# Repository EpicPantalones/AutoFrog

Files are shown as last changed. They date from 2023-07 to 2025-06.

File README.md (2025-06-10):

# AutoFrog
Welcome to AutoFrog.

This project has been deprecated in favor of AutoFrog 2.0, which is another repository I own.
## File Tree
### design
contains design files, commentary, etc. as well as the project overview and software/hardware descriptions.
### server
contains all the files and config to run on the Rpi Zero.
## userend
contains the user application and associated files.

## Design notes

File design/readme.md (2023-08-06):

# Project Overview
## Original Request
"Two cages, with misters, lights and fans, all running off 120V AC power. All devices need to be controlled by a single controller. Devices will need to be turned on/off at reprogrammable times of day, with multiple on/off times per device. Programs need to be programmable down to 1-sec intervals. Will need to track time of day, so that programs run at the same times. Need to be able to have different programs for all devices, and every day of the week. Need to be able to measure humidity and use the humidity to control the fans, based on a user set threshold. want the ability to recover from power loss and update time of day and put lights back into the state they were prior to power loss. Misters should ALWAYS start in the OFF state after power loss and NOT return to on, if they were running when power goes out. Would like a webpage to set the config file if possible, but need a way to modify programs as applicable. would be nice if RTC autochanged with daylight savings time and autosynced to remove clock drift. electric power needs to be in a box that protects any circuitry from being contacted inadvertantly."
### Device channels (by cage)
2 lights \
1 mister \
1 fan

## Electrical block diagram
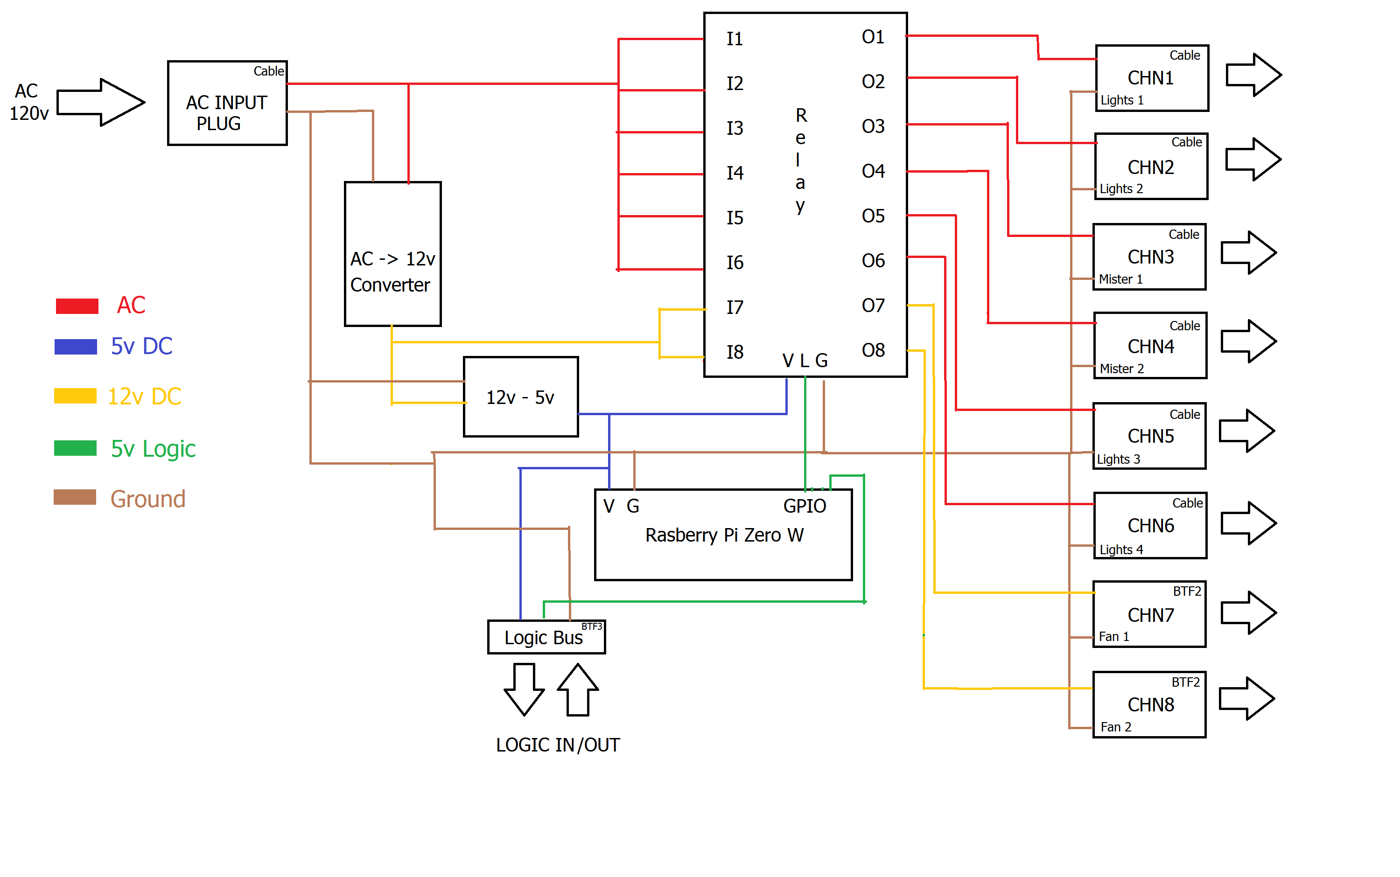
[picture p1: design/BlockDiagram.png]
Block Diagram

System has one AC input and one input on the logic bus. Has six AC channel outputs, which will vary in size depending on requirement, as well as two 12v outputs and 1 logic bus for humidity sensing. Note that for simplicity, the earth ground is omitted, and the neutral wires all connect to the same line regardless of voltage.
### Design
The power is inputted directly from 120v AC through a C13 connector with a protective fuse. This also has the master power switch. From there the power is split into two branches. The first is the AC line that goes directly to six of the eight channels on the relay, for the six AC outputs. The second branch goes to a 12v converter, which in turn produces two branches of 12v DC power: one for powering the two 12v channels, and one that is further downconverted to a 5v supply for the raspberry pi and the logical power input of the relay. The raspberry Pi's logical output is 3.3v, so there is a small level converter for the 5v required on the relay. The ground to the LC comes from the Rpi, and Va and Vb are supply by directly wiring to their respective supplies. The raspberry Pi also sends a wire out to the outside which allows the humidity sensor to send data back.

## Mechanical Design
We purchased a small clear box to contain all the circuitry. Due to time constraints, the harnessing and box are a bit rushed, but the box provides ample protection and does a good job supporting both the standoffs for the circuitry and the output connectors. Also due to the time contraints, there was not enough time to measure all of the wires, so the harnessing is not nearly as neat as I would like it to be. Next time, I would do a better job of designing the wiring layout before beginning execution of the build phase.

## Materials List:
The full list of items purchase is on amazon, link here: \
https://www.amazon.com/hz/wishlist/ls/33Y2IXWOOTIRV/ref=nav_wishlist_lists_3

### Items
- **Raspberry Pi Zero W**: the brains.
- **MicroSD card**: minimum 16GB. houses OS for Rpi
- **AZDelivery Humidity Sensor**: measures humidity in the cages to control fan speed.
- **12v DC Power Supply**: Modified standard 12v power supply. Removed the AC type A connector and barrel plug output and used just the bare wiring.
- **5v DC Converter**: downconverts the 12V line for Rpi and humidity sensors.
- **Sunfounder 8 Chn Relay**: Takes in AC or DC power and acts as a digitally controlled switch. Logical is controlled on a 5v level, which must be powered seperately from the host device.
- **HiSense Logic Level Convertor**: converts the logic level of the Rpi (3.3v) to the level of the relay (5v).
- **3Dman 15 Rocker Connector**: Used as system input, a C13 connector with a 5A fuse and a rocker switch. Fuse can be swapped for 10A if necessary.
- **Panel mount AC outlets**: Used as the channel outputs for the 6 AC channels.
- **BTF-Lightning connectors**: 2 pin version used as the connections for the 12v channels and the 3 pin version used to connect to the humidity sensor. In reality I should have gotten 2 connectors for 2 voltages, but it was a tactical decision...
- **Various Types of Wire, Standoffs, Suction Cups**

## Software Design
### Overview
Using the userend GUI, users can create and assign channels and configurations remotely from their machine. Upon confirmation, the GUI sends those configurations to the Rpi Zero, which receives them and immediately loads them into the system. The Rpi Zero has a default state in the event of power loss, and will automatically come online and begin listening again after rebooting. Users can also change the state of the channels manually, which persists until the next event in the current config file. There may be any number of configuration files, and not all configuration files are required to be assigned to a channel. Channels may share a configuration.
### User End
User Gui was designed with Tkinter, and has two main modes: configuration mode, and live command mode. In configuration mode, users may add, remove, or edit files to create custom times for the channels to be considered ON or OFF. in Live command mode, users can see the active status of the channels and can send commands to change the state of channels.
### Server
The server end uses threads to listen for commands and other than that controls some global variables that are used to determine the configuration of the system. The server controls the channels down to the second level, but it should also be noted that the inputs can only come at the minute level.

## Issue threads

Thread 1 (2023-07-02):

Purchase Approvals

EpicPantalones, 2023-07-02:
In design/readme is the current list of materials needed, as well as the link to the amazon page. I need you to read through them and approve them or bring them up for review. Yeet

sirgunthercakes, 2023-07-03:
approve all

Closed 2023-07-03.

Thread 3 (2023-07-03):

Purchase Order

EpicPantalones, 2023-07-03:
Purchasing info for the approved items. 15 items comes out to $206.37. Will wait for confirmation before purchase. Do not close this issue.

sirgunthercakes, 2023-07-03:
approve

EpicPantalones, 2023-07-03:
Order# 113-9573016-7701869 placed. Items arriving July 3 and July 6. Will post updates

EpicPantalones, 2023-07-04:
The following arrived today (now 4/13):
2 pin BTF-Lightning connectors
12v Power Supply
AZDelivery Humidity sensor
Suction cups

sirgunthercakes, 2023-07-06:
arrived 7/5
3 pin BTF lightning connectors
16 ga cable
20 ga cable
3 pin insulated cable
power rocker ac input
ac output plugs
5 volt converter
standoffs
8 channel relay
rpi zero-w

Closed 2023-07-06.

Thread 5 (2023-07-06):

Testing Checklist

EpicPantalones, 2023-07-06:
The following test must be completed for the design to be considered complete:
**Hardware Tests**
- [ ] 12v Regulator output tested
- [ ] 5v Regulator output tested
- [ ] channeled relay tested to ensure proper toggles
- [ ] Rpi outputs tested
- [ ] Humidity sensor gives valid data
- [ ] Items stay securely in mechanical housing
- [ ] AC input tested

**Software Tests**
- [ ] Rpi can read humidity sensor
- [ ] Rpi can toggle switches on and off
- [ ] Rpi can communicate across socket
- [ ] Rpi can receive input from user endpoint
- [ ] Rpi software restarts properly after power-loss

Tests may be added or removed within this thread. _Do not mark this issue as complete_

EpicPantalones, 2023-07-14:
New Test:
- [ ] logic shifter successfully changes from 3.3 to 5v

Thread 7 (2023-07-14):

Hardware Testing Results

EpicPantalones, 2023-07-14:
The following items were tested:

1. AC input plug - we discovered that the LOAD wire is the BLUE wire, the NEUTRAL is the RED, and the GROUND is the YELLOW.
2. 12 V adapter - outputs steady at 12.3V
3. 5 V adapter - outputs steady at 5.02V
4. 8 Channel relay - the part functions just fine. Note - we should use the right pair of inputs so that it defaults to CLOSED in a powered state.
5. Rasberry Pi Zero - we tested the GPIO using gpio_test.py. It turns out that Rpis operate at a 3.3V logic level, so we are purchasing new logic shifters to get the output we need for the relay.

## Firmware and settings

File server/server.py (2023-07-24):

import threading
import socket
import os

CWD = os.getcwd()
KILLSWITCH = True
'''
Socket server runs on an infinite loop. You can start it in a thread
to prevent the server from blocking the rest of the program.
'''
def start_socket_server(host, port):
    # Create a TCP socket
    server_socket = socket.socket(socket.AF_INET, socket.SOCK_STREAM)
    
    # Bind the socket to the host and port
    server_socket.bind((host, port))
    
    # Listen for incoming connections
    server_socket.listen(1)
    print(f"Server started. Listening on {host}:{port}")
    
    try:
        while KILLSWITCH:
            # Accept a connection
            client_socket, client_address = server_socket.accept()
            print(f"Accepted connection from: {client_address}")
            
            # Handle the client connection in a new thread
            threading.Thread(target=handle_client, args=(client_socket,)).start()
    finally:
        server_socket.close()

'''
handle_client spawns everytime the server gets a connection. It receives
a message and then directs it into handle_message, where a message is returned.
'''
def handle_client(client_socket):
    while True:
        # Receive data from the client
        data = client_socket.recv(1024).decode()
        
        if not data:
            break  # No more data received, exit the loop
        
        # Handle the received message in a new thread
        threading.Thread(target=handle_message, args=(client_socket, data)).start()

    # Close the client socket
    client_socket.close()

'''
handle_message will perform the action from the server
spawns from the thread handle_client
'''
def handle_message(client_socket, message):
    # DEBUG Printing the received message
    print(f"Received message: \"{message}\"")
    OK = True
    args = message.split()
    print(args)
    commands = ["UPDATEREGISTRY","REQUESTLIVESTATUS","LIVECOMM"]
    if args[0] not in commands:
        response = "ERROR comm-not-recognized"
    else:
        if args[0] == "UPDATEREGISTRY":
            reached = False
            edits = []
            deletes = []
            for i,arg in enumerate(args):
                if i == 0:
                    continue
                if arg == "DELETES":
                    reached = True
                elif reached:
                    deletes.append(arg)
                else:
                    edits.append(arg)
            # function that will update system
            print(f"edits:{edits}")
            print(f"deletes:{deletes}")
            response = "RECEIVED"
        elif args[0] == "REQUESTLIVESTATUS":
            # will need to create system to grab status...
            response = "RECEIVED 1 0 1 0 1 0 1 0"
        elif args[0] == "LIVECOMM":
            # will need to create system to grab status...
            response = "RECEIVED COMPLETE"
    client_socket.sendall(response.encode())

# Usage example
if __name__ == "__main__":
    host = ""  # Leave empty to listen on all available interfaces
    port = 1234  # Choose a port number
    
    start_socket_server(host, port)

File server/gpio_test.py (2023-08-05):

import RPi.GPIO as GPIO
from enum import IntEnum
import signal
import time

'''
This IntEnum contains the pin number that should be used for each
channel. Change them here, and the entire rest of the program changes.
Pins can also be individually addressed with "C.NUM"
'''
class C(IntEnum):
    ONE = 11
    TWO = 12
    THREE = 13
    FOUR = 15
    FIVE = 16
    SIX = 18
    SEVEN = 22
    EIGHT = 29
    
'''
A refence list that can be used to iterate through pins;
calling CHAN[#] will return the correct pin number.
'''
CHAN = [C.ONE, C.TWO, C.THREE, C.FOUR, C.FIVE, C.SIX, C.SEVEN, C.EIGHT]
            
'''
function for setting pins
for state - True is on, False is off
'''
def set_pin(pin,state):
    assert state in [True,False], f"{state} is not a valid state."
    if state:
        GPIO.output(pin, GPIO.HIGH)
    else:
        GPIO.output(pin, GPIO.LOW)

'''
test function - will blink the lights on
and off for "count" times
'''
def blinker():
    for pin in CHAN:
        set_pin(pin,True)
        print(f"Pin {pin} ON")
    time.sleep(5)
    for pin in CHAN:
        set_pin(pin,False)
        print(f"Pin {pin} OFF")

'''
init function for controlling the setup of the board when program is first run.
This should handle all the setup for the program and loading in things from files
etc. It should also load the server thread that listens for incoming commands.
'''
def init():
    # Set the GPIO mode
    GPIO.setmode(GPIO.BOARD)
    for pin in CHAN:
                GPIO.setup(pin, GPIO.OUT)
    # Load in the default states
    
    # Load in the config
    
    # Start the server thread (should it be thread?)

'''
This should run until interrupted. The server thread should 
call here for interrupts?
'''
def loop():
    while True:
        # listen for things... react to them...
        blinker()

'''
What to do if the program is allowed to exit cleanly (Ctrl+C only)
'''
def signal_handler(sig, frame):
    GPIO.cleanup()
    exit(0)

if __name__ == "__main__":
    signal.signal(signal.SIGINT, signal_handler)
    init()
    loop()
    

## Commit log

2023-07-24 app features ready; begin cross device tests
2023-08-06 added button sounds; improved parse logic
2024-08-23 added initial PCB design elements
    [pcb_main.kicad_pcb, pcb_main.kicad_sch]
